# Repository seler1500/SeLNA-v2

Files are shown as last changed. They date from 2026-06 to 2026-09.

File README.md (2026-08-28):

# SeLNA v2  
#### High performance, low cost filtered LNA 
<details><summary>Naming scheme, serial numbers</summary>  

v2.a.b  
v2 = SeLNA v2   
a = filter count   
b = revision  
v2.2.6 = double filtered SeLNA v2, revision 6  

2.a.b.cccc.dddd  
2 = SeLNA v2  
a = filter count  
b = revision  
cccc = center frequency  
dddd = board SN  
2.2.6.1680.0021 = double filtered SeLNA v2, revision 6, 1680 MHz center frequency, board number 21  

</details>

<details><summary>Specs</summary>  

Frequency range: 100 ... 3600 MHz (filter dependent)  
Supply voltage: 3.15 ... 5.25 V  
Supply current: typ. 140 mA @ 5 V   
Operating temperature: -30 ... +75°C (case)  
Storage temperature: -40 ... +85°C  
Noise figure: typ. 0.45...0.6dB (L-band, v2.1.5)   
50Ω matched input/output  
</details>

## Assembly  
<details>
<summary>Done soldering? Received a sample? Here's a "quick" start guide.</summary>
  
### Step 1 - cleanup and preparing the components
SeLNA v2 uses chinese bias tee enclosure, as that was the cheapest option to include connectors, lid and the screws. You can easily find it on aliexpress by searching for "RF bias tee".  
After reflow soldering the board, it's recommended to wash it with isopropyl alcohol or other electronics-safe solvent to remove any flux and solder residues.  
**Make sure to very neatly clean up the MMIC areas from leftover solder paste (nylon brush + isopropyl alcohol work well); otherwise it will skew the bias current and might cause weird behaviour.**  
SMA connector probes need to be shortened to 2 ±0.25 mm, teflon insulator should be flush with the inner enclosure surface.

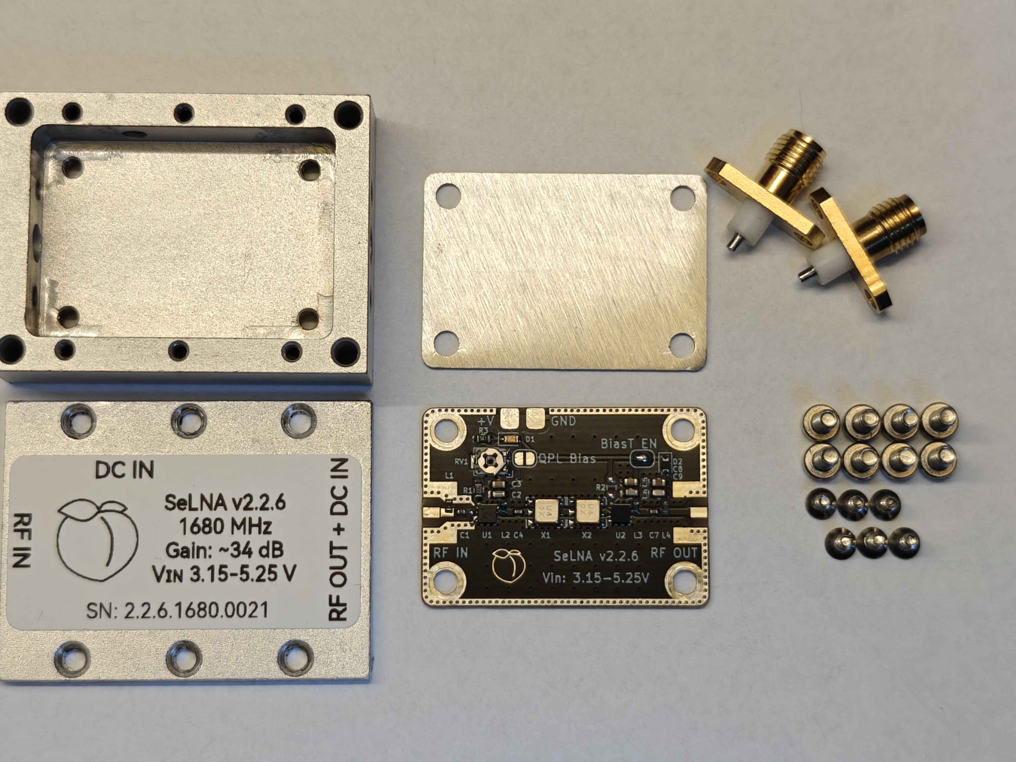
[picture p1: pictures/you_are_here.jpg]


Chinese enclosures vary in quality and dimensions. There seem to be three versions of the enclosure - two of them require a 0.8 mm spacer under the PCB.
If the clearance between SMA probe and PCB looks like this, you need to add a spacer:

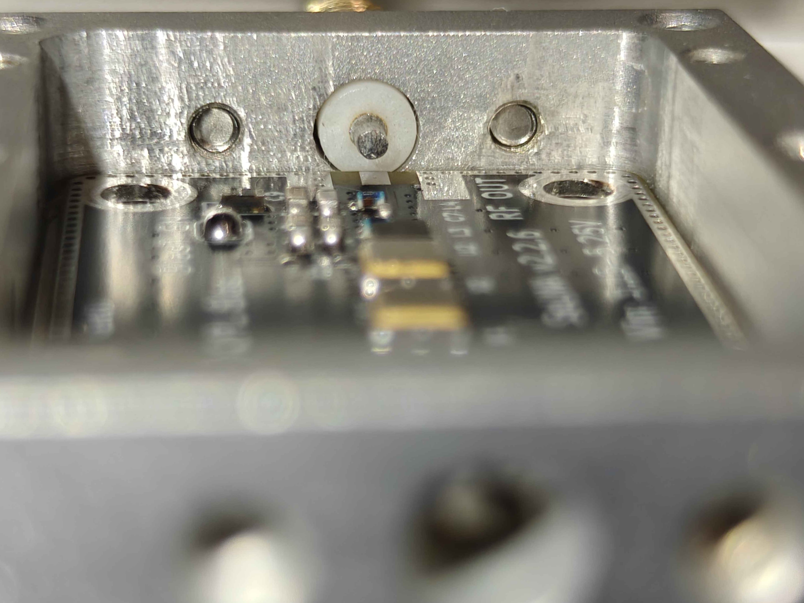
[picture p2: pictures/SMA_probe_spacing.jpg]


If there's any manufacturing defects like these:

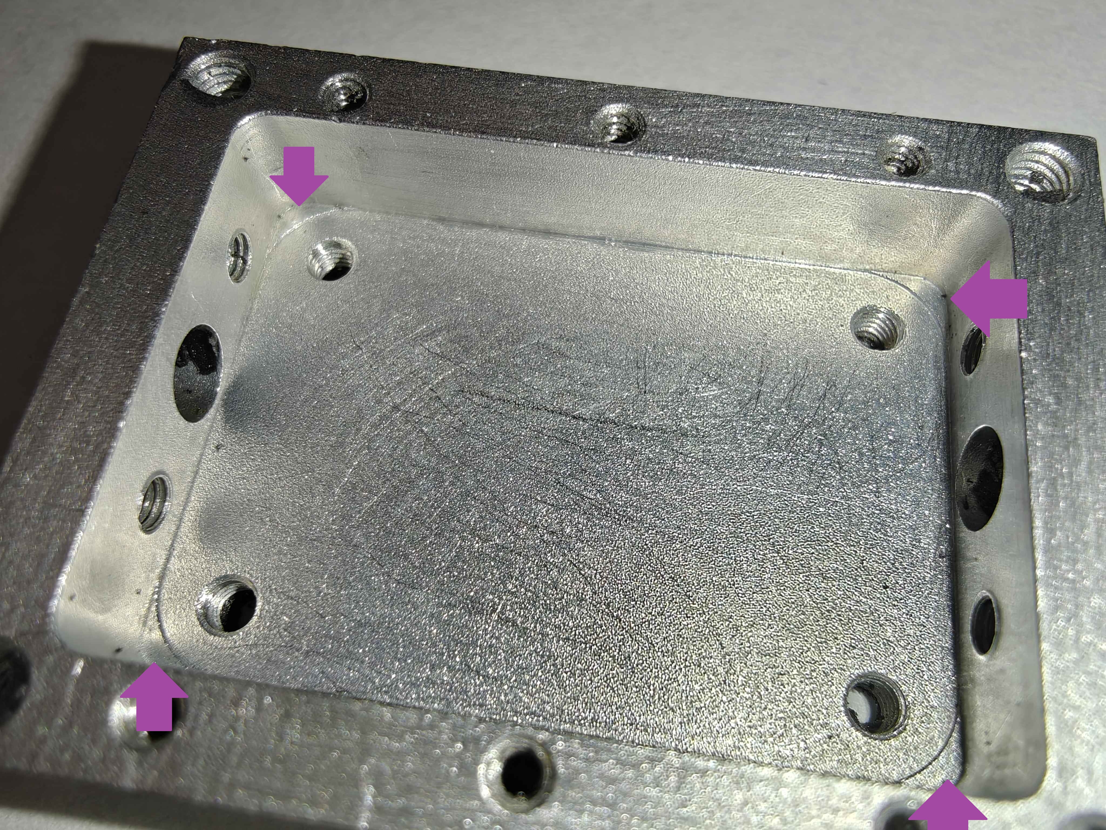
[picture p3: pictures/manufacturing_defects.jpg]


You will need to either grind/mill them down manually, or adjust the spacer to fit around the raised edges.  
If there are no manufacturing defects, and the SMA probe clearance looks like this - you can move to the next step:

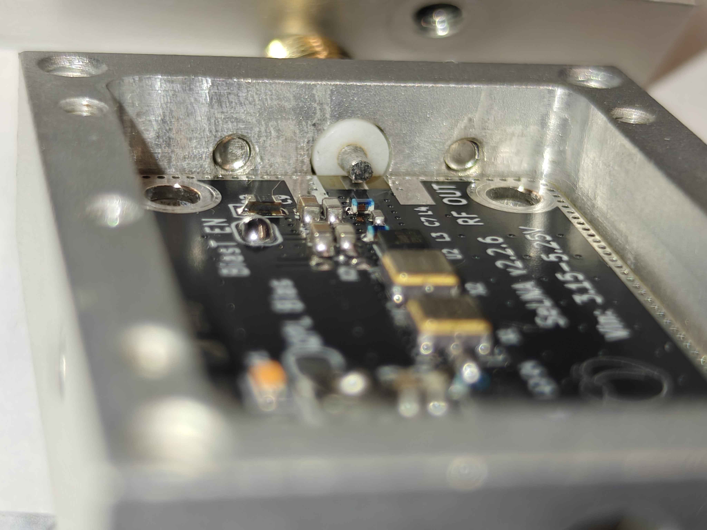
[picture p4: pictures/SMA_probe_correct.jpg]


Which is... making sure the enclosure is conductive. Quick multimeter continuity test will tell, without pushing down on the probes. Some of the enclosures arrive anodized, you will need to get rid of this coating at least under SMA connectors and under the PCB. Either sanding or etching in 5-10% NaOH works, remember about all safety precautions when working with corrosive substances, or with aluminum dust!

### Step 2 - measuring and setting first stage bias current

Set your power supply to 4.2-4.5V (unless you are planning to use the LNA with different input voltage), connect the ground to the PCB ground, and positive to a positive lead of your multimeter.  
Set it to DC current measurement, <200mA range. Probe "QPL Bias" pad with the other lead as shown.  

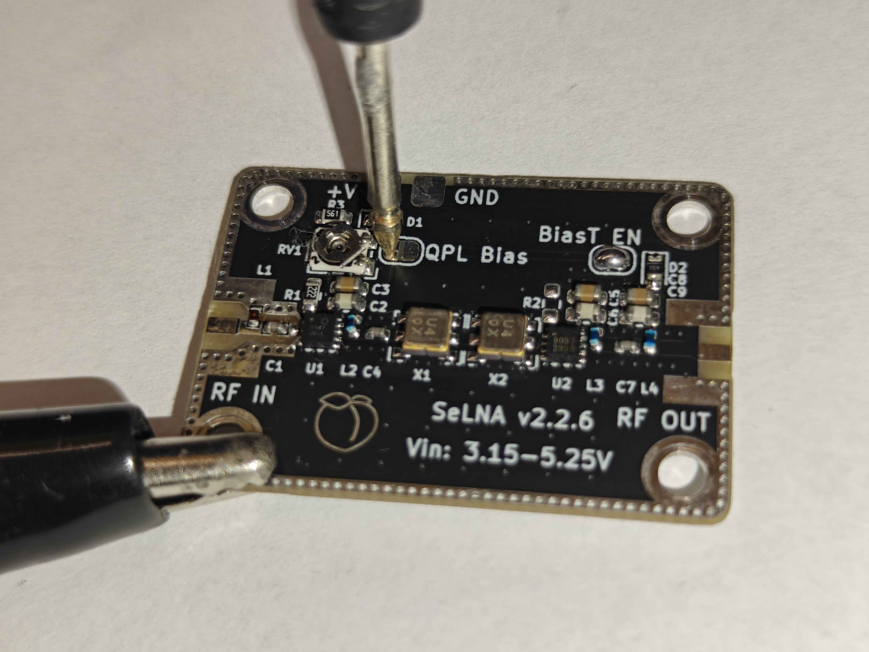
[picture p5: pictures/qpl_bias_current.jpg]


Using the potentiometer, set the bias current to 65mA. Once the bias current is set, you can solder the "QPL Bias" jumper. Solder the "BiasT EN" jumper as well if you wish to enable bias tee power for your LNA.

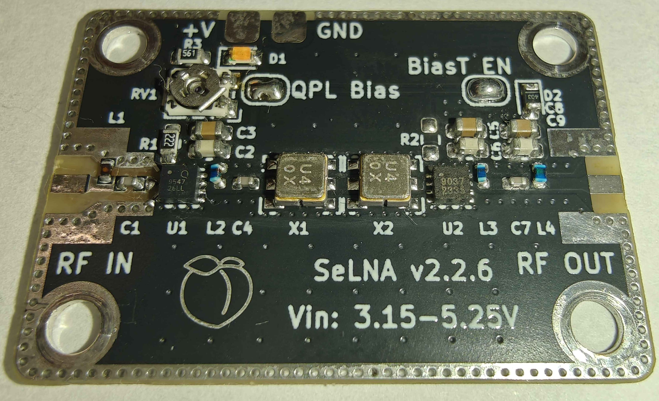
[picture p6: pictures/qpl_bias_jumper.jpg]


### Step 3 - installing the PCB and connectors

Start with dropping the PCB (or spacer and then PCB) inside the enclosure. Install all 4 mounting bolts, without tightening them for now.  
If you'd like to weatherproof your LNA, now is the time to apply a thin layer of sealant on SMA connector mating surfaces (and in their bolt holes).
Insert both SMA connectors, install their mounting bolts (without tightening for now).  
Gently press down on the connector:  
  
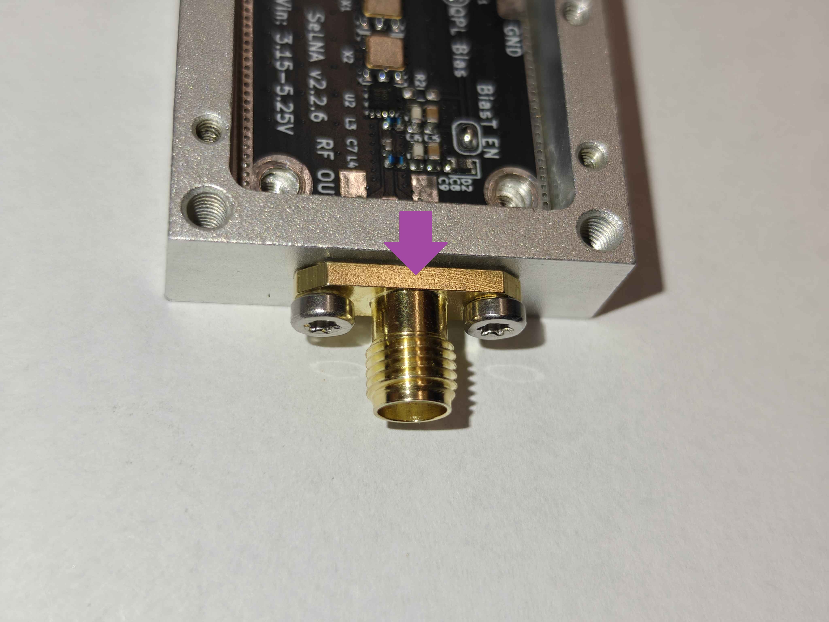
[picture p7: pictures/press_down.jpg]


and torque the mounting bolts to 0.4 Nm (40 Ncm).
Once the connectors are secured, you can start aligning the PCB with SMA probes.  

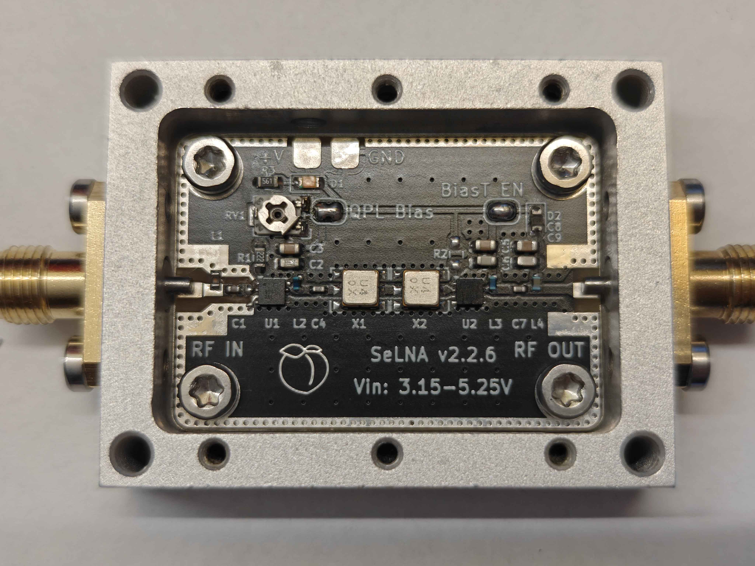
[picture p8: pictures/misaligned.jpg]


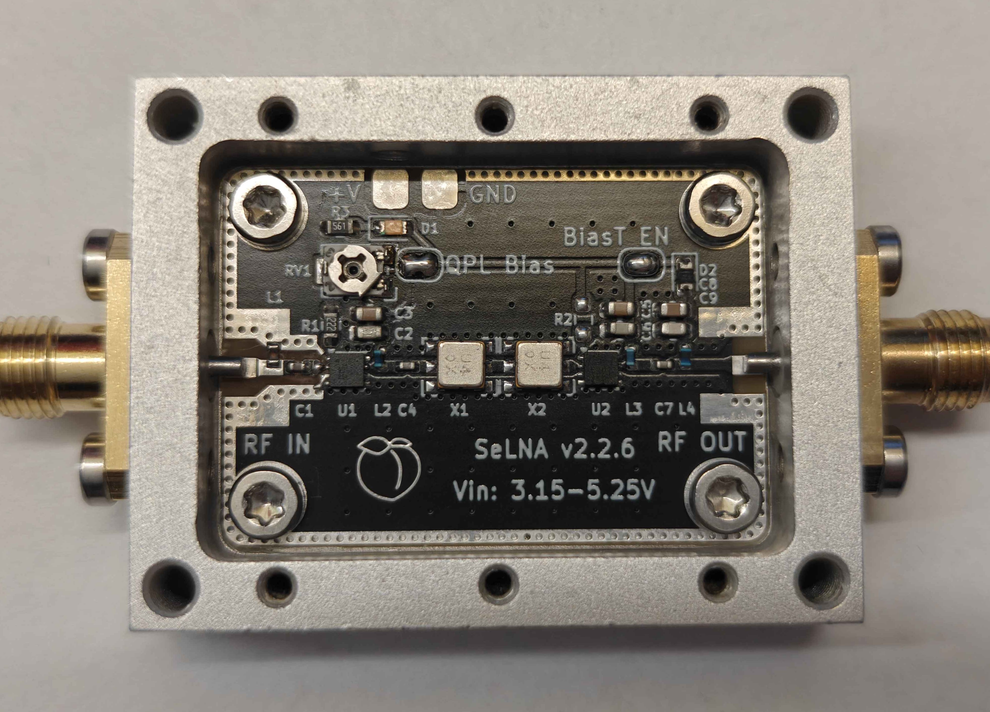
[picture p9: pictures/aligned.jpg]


Once aligned, torque the mounting bolts to 0.4 Nm (40 Ncm).  
Now you can solder the SMA probes to the PCB. Once soldered, they should look like this:  

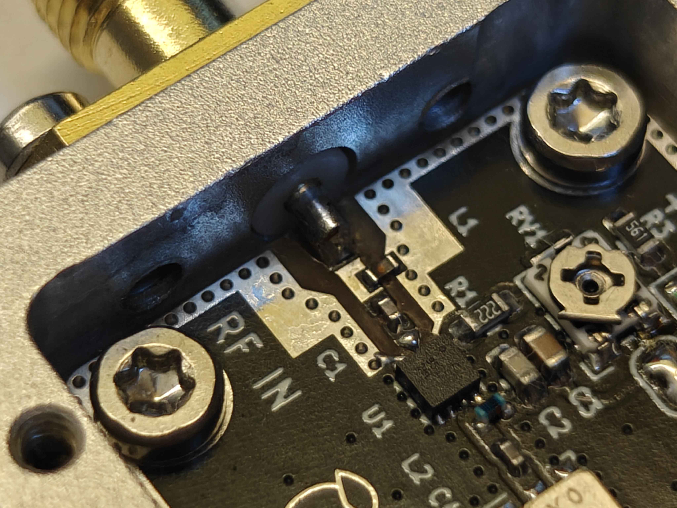
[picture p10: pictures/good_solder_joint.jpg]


and definitely not like this:

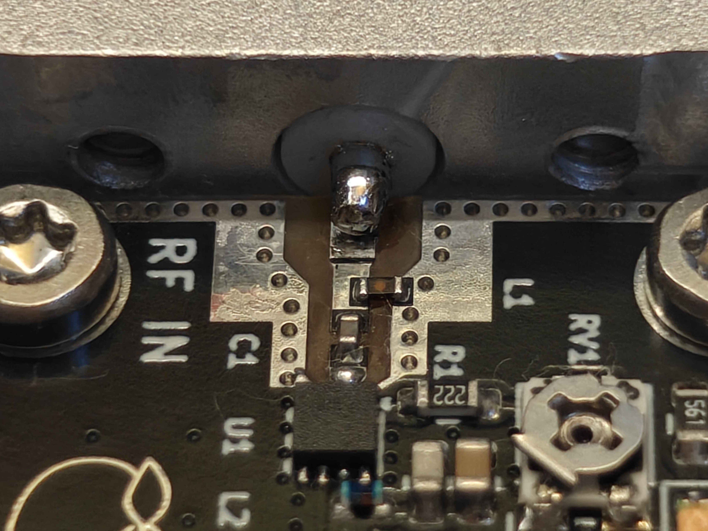
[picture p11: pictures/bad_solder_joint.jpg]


If you'd like to power your LNA externally, install the dc pass-trough now. Otherwise install an M3x4 plug.
If you chose to weatherproof your LNA, apply thin layer of sealant on the lid mating surface, and over the PCB mounting holes (from the outside).
You can install the lid afterwards.

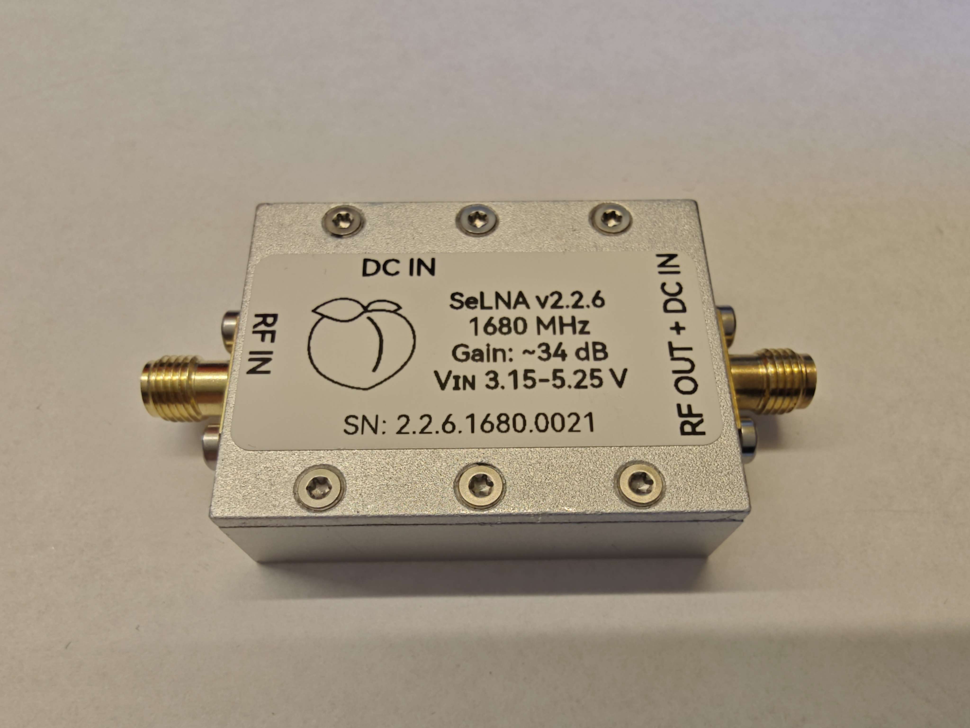
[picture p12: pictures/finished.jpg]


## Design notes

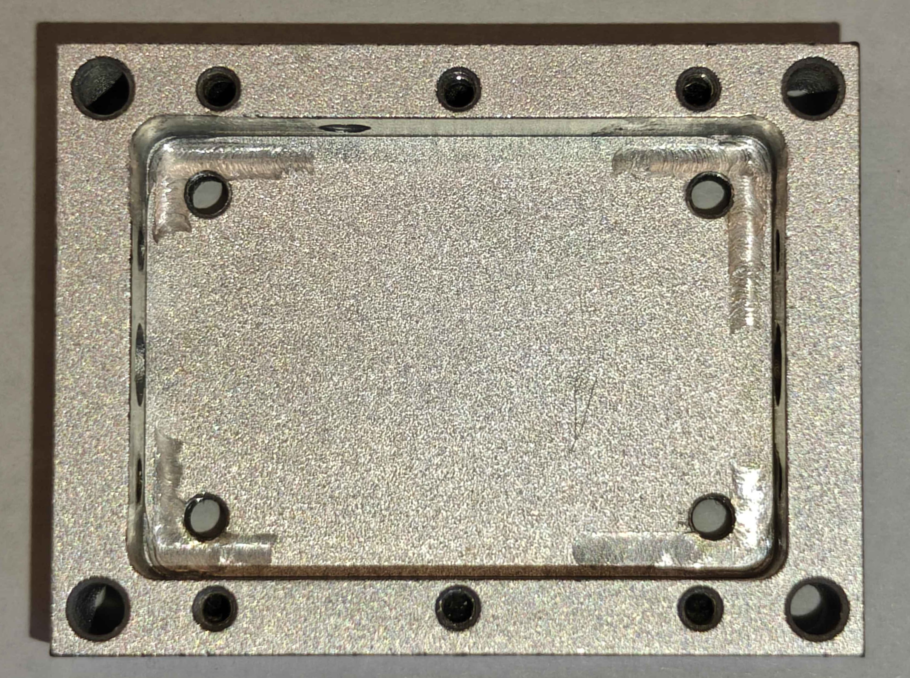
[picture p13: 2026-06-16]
pictures/fixed.jpg

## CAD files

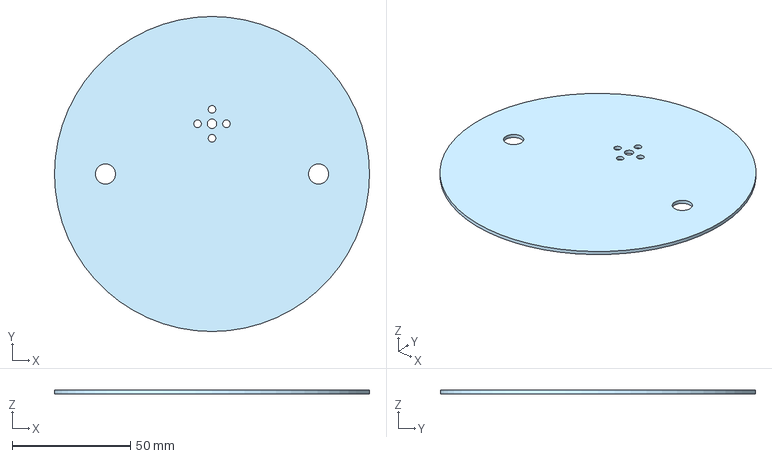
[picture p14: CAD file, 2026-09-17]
accessories/sheet metal dereksgc v5 helix ground plane (2250 MHz).step
133.0 x 133.0 x 1.50 mm

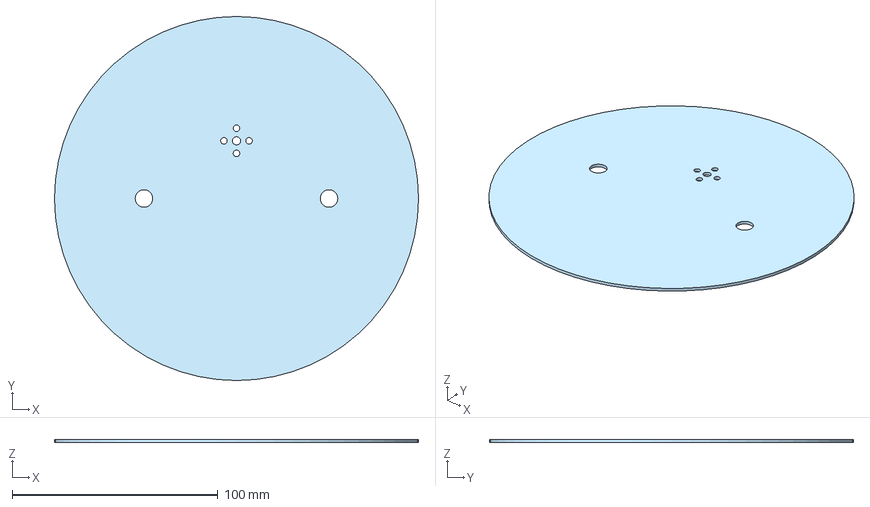
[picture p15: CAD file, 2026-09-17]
accessories/sheet metal dereksgc v5 helix ground plane (1700 MHz).step
177.0 x 177.0 x 1.50 mm

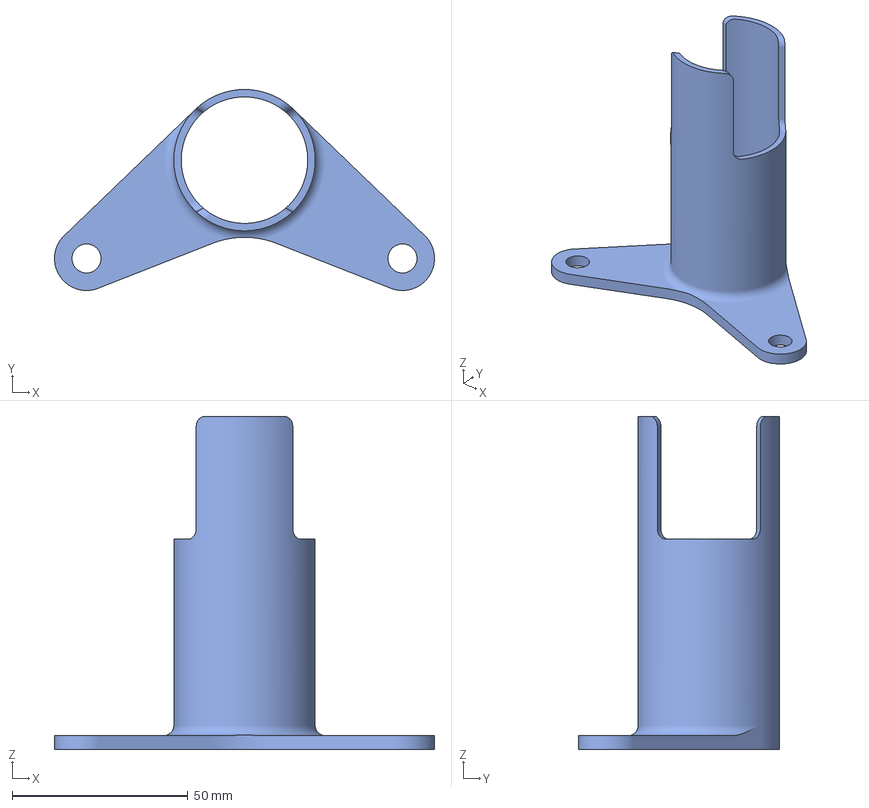
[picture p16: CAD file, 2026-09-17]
accessories/SeLNA v2 x dereksgc v5 helix mount (1700 MHz).3mf
108.2 x 57.2 x 95.0 mm

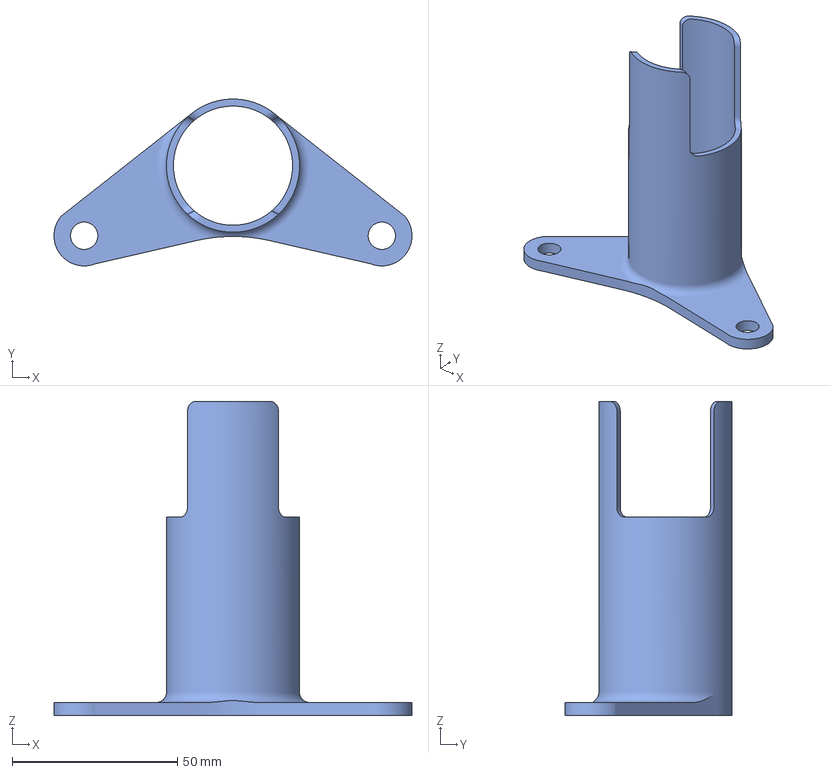
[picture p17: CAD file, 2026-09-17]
accessories/SeLNA v2 x dereksgc v5 helix mount (2250 MHz).3mf
108.2 x 50.4 x 95.0 mm

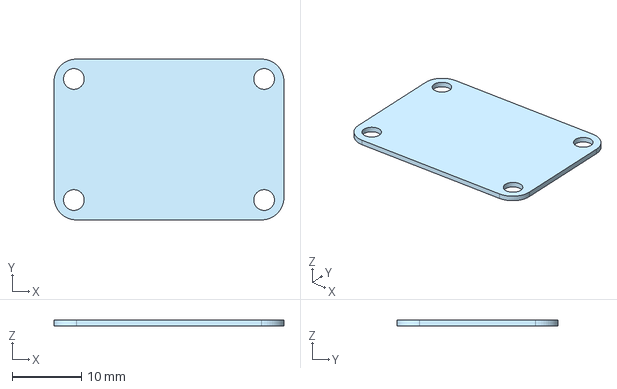
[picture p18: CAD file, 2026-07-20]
accessories/alu_spacer_v2.step
33.2 x 23.2 x 0.8 mm

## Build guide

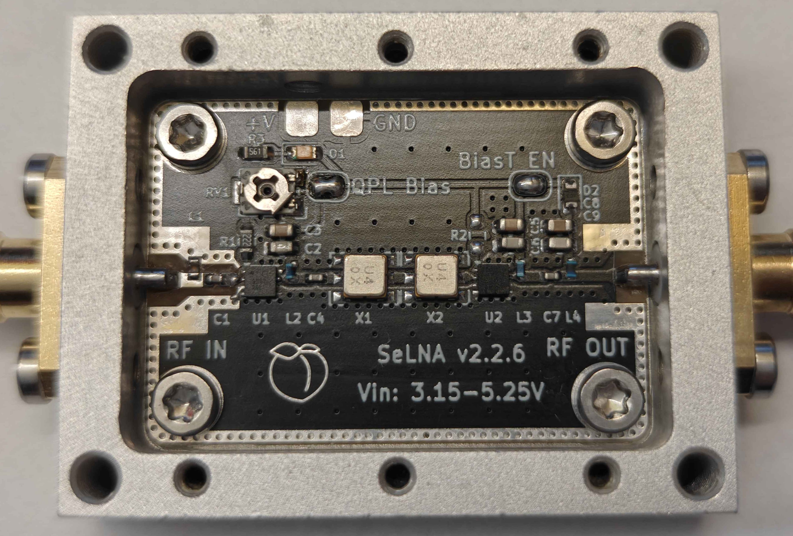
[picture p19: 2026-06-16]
pictures/assembled.jpg

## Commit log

2026-07-20 pcb spacer
    [alu_spacer_v2.step]
2026-09-17 add helix ground planes
    [sheet metal dereksgc v5 helix ground plane (1700 MHz).step, sheet metal dereksgc v5 helix ground plane (2250 MHz).step]
2026-09-17 add LNA covers/40mm LNB mounts
    only for use with compatible ground planes (mind the SMA - bolt hole distances)
    [SeLNA v2 x dereksgc v5 helix mount (1700 MHz).3mf, SeLNA v2 x dereksgc v5 helix mount (2250 MHz).3mf]
2026-09-17 fix wrong SMA bolt pattern
    [sheet metal dereksgc v5 helix ground plane (1700 MHz).step, sheet metal dereksgc v5 helix ground plane (2250 MHz).step]
2026-10-21 ground plane templates
